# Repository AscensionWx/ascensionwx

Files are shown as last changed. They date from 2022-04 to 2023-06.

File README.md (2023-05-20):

# AscensionWx

AscensionWx is an open source weather station network supporting the Kanda Weather and U.S. and European communities. The hardware ranges from 3D-printed DIY sensors to commercially available weather stations, and aims to improve weather data collection and forecasting. 

Currently, over 100 stations are online and receiving digital rewards from the weather data they provide to the Telos Blockchain.

## Supported Ground Stations

| 3D-printed AscensionWx     |  SenseCAP LoRaWAN 8-in-1  |  SenseCAP S2101 T+RH sensor |
:-------------------------:|:-------------------------:|:-------------------------:
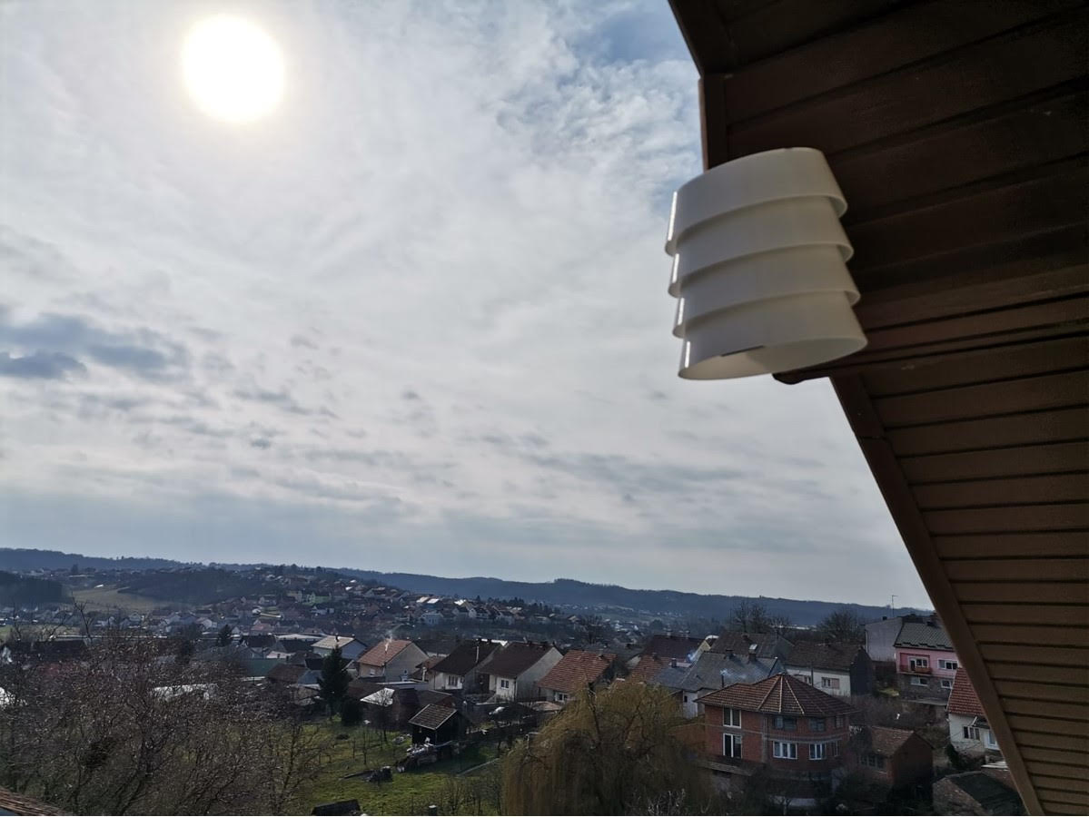
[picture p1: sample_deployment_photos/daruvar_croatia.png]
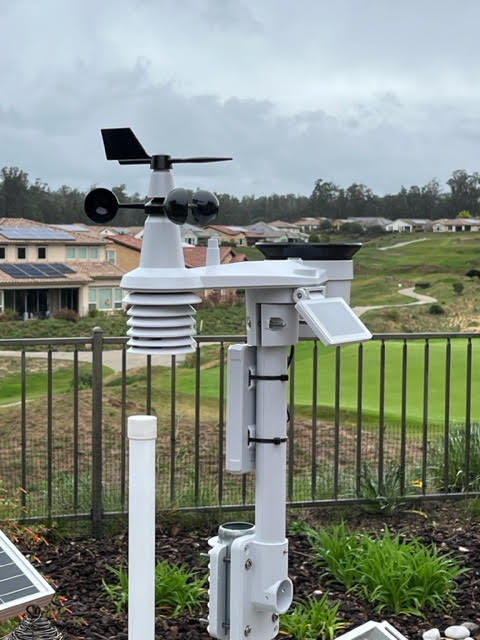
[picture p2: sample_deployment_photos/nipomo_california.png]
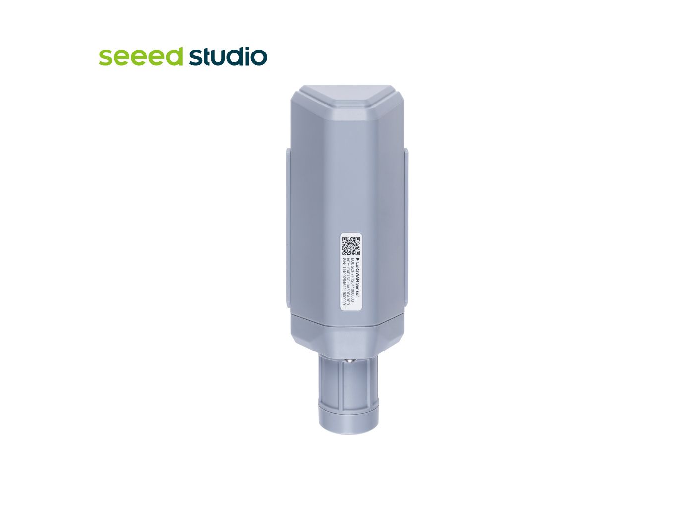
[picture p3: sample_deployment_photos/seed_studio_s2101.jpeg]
|   |   |   |

## Web Applications

Live Station Map:
- http://app.kandaweather.net:5001

Live station-specific app:
- https://ascensionwx-dashboard.vercel.app/graph?devname=brownlotguru

NFT Market (in progress):
- https://nft.kandaweather.net

## Engineering Diagram

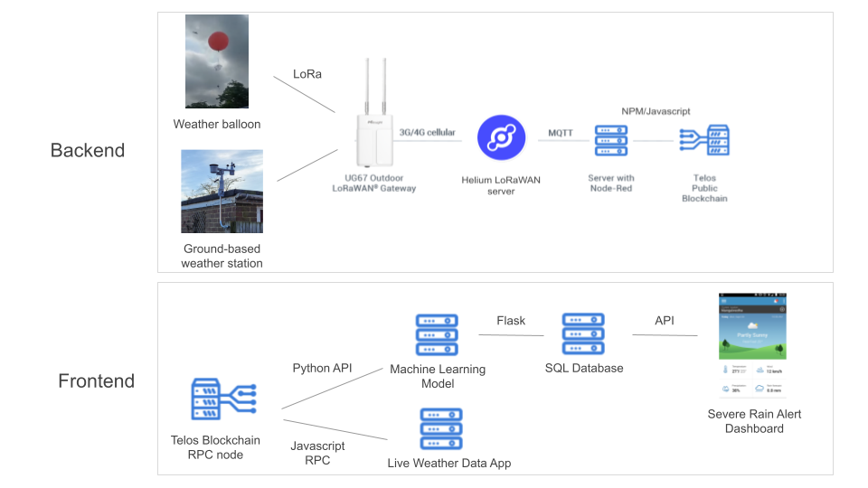
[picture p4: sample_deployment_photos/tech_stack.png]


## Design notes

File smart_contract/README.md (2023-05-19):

# Blockchain Smart Contract
The native Antelope C++ smart contract files for ground-based Weather Miners

For Kanda Weather (Africa) and AscensionWx (U.S.), and open under MIT license.

Features:
- Temperature/humidity QC quality score based on nearby stations
- Sends mining rewards to weather station owners at "Lock-In" USD rates
- Builder royalties issued for those that 3D-print stations for other users
- Sends rewards as either native or Telos EVM

Dependencies:
- 1.8.0 eosio CDT

Utilizes other on-chain contracts
- delphioracle
- eosio.evm 

Future additions:
- Device-specific digital signatures

Currently deployed as the ascendweathr contrct on Telos Mainnet
https://explorer.telos.net/account/ascendweathr

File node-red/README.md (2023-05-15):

These files are used for handling of the LoRaWAN messages. Hardware examples include:

- UG67 and UG65 Milesight IoT gateway
- Raspberry Pi
- Small AWS EC2 instance

These flows can be imported by:

1. Installing Node-RED globally
2. Updating your $HOME/.node-red/package.json file to include the following property.
```
    "dependencies": {
        "node-red-contrib-telos-eosio": <path to where you will run node-red>
    }
```
  And then run "npm install" to take effect

3. Go to the location where you want to run node-red and the flow file. Cloning external git repo
```
git clone https://github.com/sunburntcat/node-red-contrib-telos-eosio.git
```
4. Install packages
```
cd node-red-contrib-telos-eosio
npm install
```
5. Running node-red with the pre-built flow file
```
node-red <flow_filename>.json
```
6. Configuring MQTT and other nodes with appropriate credentials

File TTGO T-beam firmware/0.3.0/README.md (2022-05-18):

These files are a stable release of the Arduino-based firmware for the Kanda Weather Sensors. It includes:

- Miner authentication over the ESP32's web server
- Weather observations every 15 minutes over Helium/TheThingsNetwork
- Real time clock adjustments periodically from the GPS unit
- GPS geolocation messages during the night

Not supported:

- On-device signatures

It is recommended the user have a blank Arduino environment. And then unzip the dclimateiot_arduino_libs file in the relevant Arduino "libraries" folder.

Note that when you are ready to upload the firmware, you must first adjust the lmic_config file located in the library to match the correct frequency. 

Also note, that the correct LoRaWAN keys need to be loaded into the credentials.h file. For OTAA, DevEUI and AppEUI need to be little-endian (LSB).This can be interpretted from Helium or TheThingsNetwork consoles. The AppKEY can be big-endian.

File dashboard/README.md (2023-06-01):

## AscensionWx Live Weather Dashboard

The live weather dashboard originally written by Bayang Mounmo is being maintained in the following repository:

https://github.com/sunburntcat/ascensionwx-dashboard

Example live station page:
https://ascensionwx-dashboard.vercel.app/graph?devname=brownlotguru

Stations can be queried by typing in the name in the "Station" box. For example, to get data from the station at the University of Uyo, type "astaluniuyo1" and click the "Plot" button.

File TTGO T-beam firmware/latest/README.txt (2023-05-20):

Changes in this version:

Remove dead ABP code
Added sleep_light_millis()
Added MESSAGE_PENDING variable that gets set to false on TXCOMPLETE
Wait exactly until RX windows close after observation (saves battery)
wait_for_gps_time_and_location wait 10 seconds for GPS serial
GPS on for 5 minutes roughly every 3 days
Sends GPS message after on for 5 minutes
Remove RTC sync with every observation (was causing 1-second delay)

Todo:
GPS always 5 minutes every 3 days
GPS message 5 second wait for TX/RX output, then send
Send data every 20 minutes?

Test:

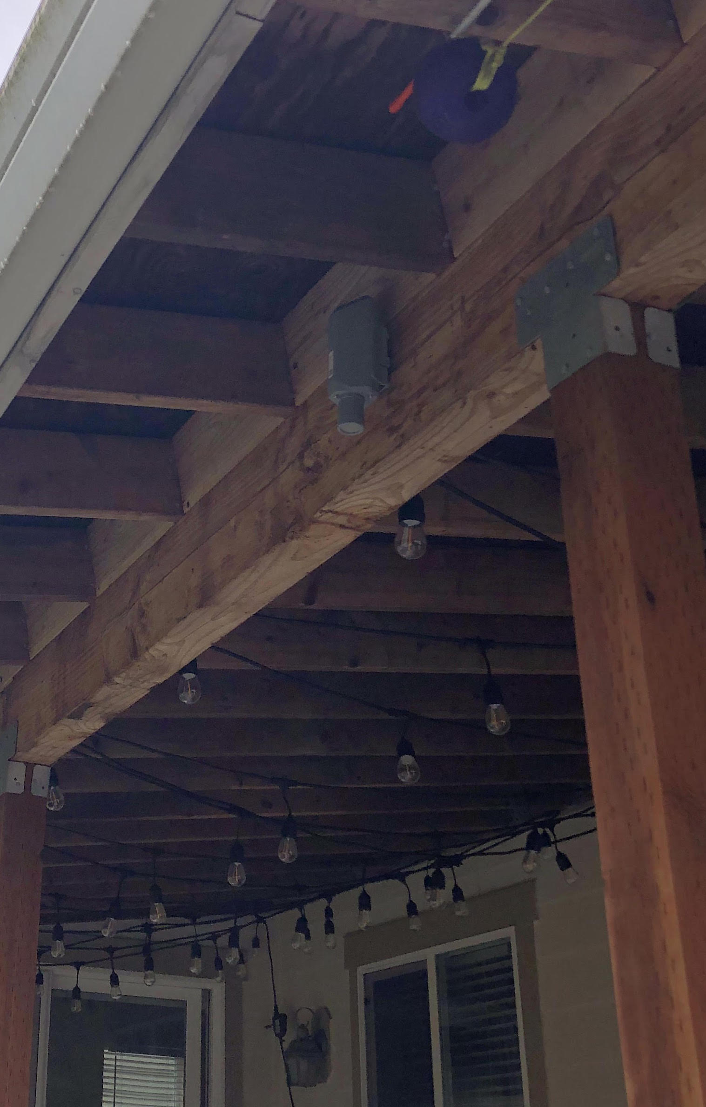
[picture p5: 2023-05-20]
sample_deployment_photos/tacoma_washington.jpeg

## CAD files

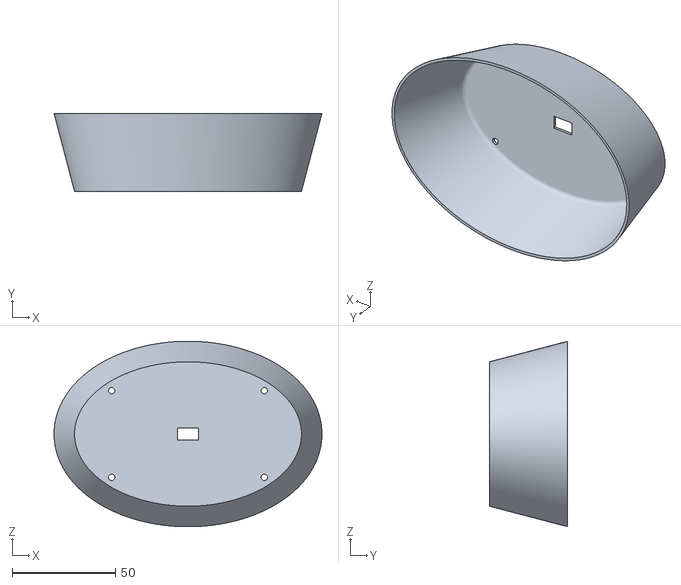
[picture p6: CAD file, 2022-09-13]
3D-print-enclosure/stl/Top.STL
129.9 x 38.0 x 89.9

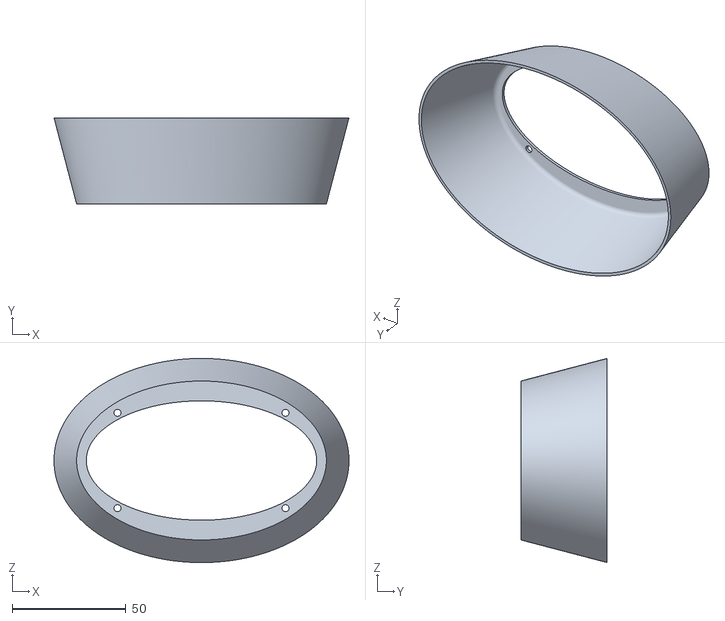
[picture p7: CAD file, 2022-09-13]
3D-print-enclosure/stl/Shroud.STL
129.9 x 38.0 x 89.9

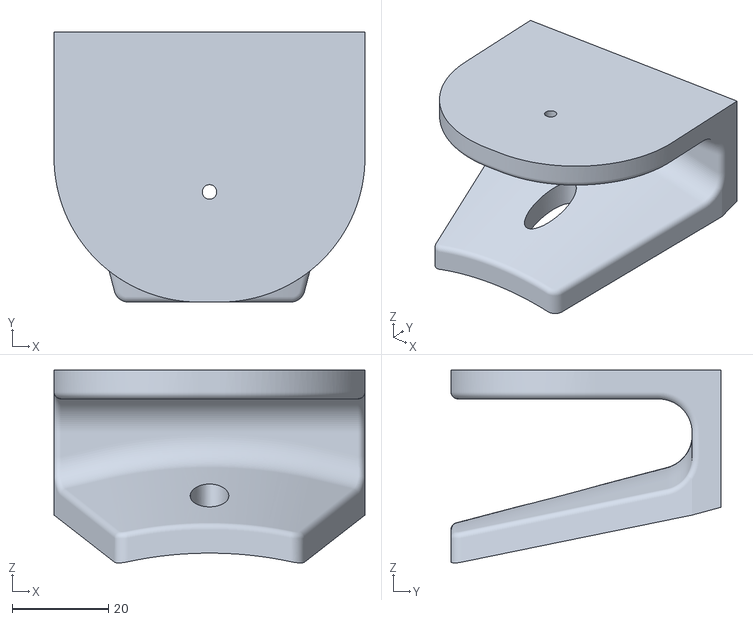
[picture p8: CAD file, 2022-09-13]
3D-print-enclosure/stl/Hook.STL
64.5 x 56.0 x 40.0

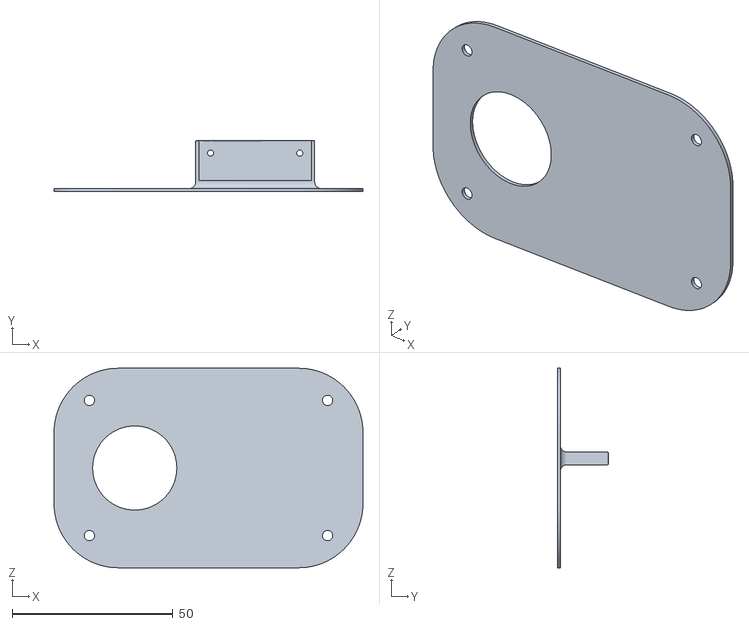
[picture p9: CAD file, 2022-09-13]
3D-print-enclosure/stl/Mid Plate.STL
96.0 x 16.0 x 62.0

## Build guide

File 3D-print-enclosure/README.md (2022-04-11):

This folder includes files used for 3D printing the 6-inch enclosure designed by Kanda.

Note that the folder "stl" includes the basic 3D CAD files. These can be viewed online or modified with commercial webapps and software. For example, TinkerCAD or Fusion360

The "gx" folder includes files for direct 3D printing. Please only use the gx files for your corresponding printer. If you have a different 3D printer, please download the files in the "stl" folder and import into a Slicer software suitable for your printer. If the prints turn out successfully, feel free to create a pull request to upload your own Sliced files to the "gx" folder.

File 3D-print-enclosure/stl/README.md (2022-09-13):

This folder includes basic CAD models

To produce a full sensor enclosure, the one needs to print multiples of some pieces. If your printer has two nozzles and a large enough print bed, you could try printing two of the items together to save time.

Here is the full list:

- 1 Top
- 3 Shroud
- 1 Mid Plate
- 1 Hook

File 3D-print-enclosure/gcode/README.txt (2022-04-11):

If you have success with printing the files, upload your Slice files here!

Place them in a folder with your printer and filament type and include a README file with a short description of your settings.

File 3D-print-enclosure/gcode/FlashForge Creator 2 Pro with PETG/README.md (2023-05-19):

All "slice" files were sliced with FlashPrint5 for the FlashForge Creator Pro 2 with PETG filament. 

Bed temperature was chosen to be 85 degrees and nozzle temperature of 240 celsius

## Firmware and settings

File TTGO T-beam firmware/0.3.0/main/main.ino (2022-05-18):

/*

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
Unless otherwise stated, all other files under this Arduino program
fall under the GPL license.

This code requires the MCCI LoRaWAN LMIC library
by IBM, Matthis Kooijman, Terry Moore, ChaeHee Won, Frank Rose
https://github.com/mcci-catena/arduino-lmic

*/

#pragma once

const char * APP_NAME = "dClimateIot";
const char * APP_VERSION = "0.3.0";

#include "config_hardware.h"

#include <Arduino.h>
#include <lmic.h>
void lorawan_register(void (*callback)(uint8_t message));

#include "soc/soc.h"
#include "soc/rtc_cntl_reg.h"

#include "config_user.h"
#include "rom/rtc.h"
#include <TinyGPS++.h>
#include <Wire.h>
#include <Math.h>
#include <axp20x.h>

#include <LoraMessage.h>
#include <LoraEncoder.h>

#include <WiFi.h>

bool SSD1306_FOUND = false;
bool BME280_FOUND = false;
bool SHT21_FOUND = false;
bool SPL06_FOUND = false;
bool AXP192_FOUND = false;
bool RELAIS_ON = false;

// Message _counter, stored in RTC memory, survives deep sleep
RTC_DATA_ATTR uint32_t COUNT = 0;

int SEND_INTERVAL;
bool GATEWAY_IN_RANGE;
String DOWNLINK_RESPONSE = "";
bool AUTHENTICATED = false;
bool BATT_CHARGING = false;
int8_t APPROX_UTC_HR_OFFSET = 0;

uint64_t last_seen_charging = 0;
uint64_t last_time_refresh = 0; // Most straight forward to store this as millis()
float time_drift = 0;
uint64_t last_gps_refresh = 0;

// Define how often to do time sync of esp32 clock with GPS
//   ... increase occurence to get better unix time stamps
//   ... decrease to save battery ; lower risk of GPS module wearing out with 1000s of on/off commands on monthly time frame
const int hr_milliseconds = 60*60*1000;
const int time_refresh_rate = hr_milliseconds*3; // How often we attempt time sync
const int wifi_on_millis = 3*60*1000;

// Launch-specific values
float SFC_PRESSURE = 0.0;
bool IF_WEB_OPENED = false;
bool IF_LAUNCHED = false;
uint8_t LAUNCH_ID[8] = { 0xFF, 0xFF, 0xFF, 0xFF, 0xFF, 0xFF, 0xFF, 0xFF } ; // For launch_id downlink

// Stores all the measured temperatures in the past 24 hours
int8_t temperatures[100];

// Set web server port number to 80
WiFiServer SERVER(80);
WiFiClient CLIENT;

// Used in power management
//  Will be used to turn off GPS, check if charging, battery etc
AXP20X_Class axp;


// -----------------------------------------------------------------------------
// Application
// -----------------------------------------------------------------------------



//////////////////////////////////////////
///////////// ARDUINO SETUP //////////////
//////////////////////////////////////////
void setup() {
  
  // Debug
  #ifdef DEBUG_PORT
  DEBUG_PORT.begin(SERIAL_BAUD);
  #endif

  // Helps to briefly wait for serial baud
  while ( millis() < 500 );
  
  Wire.begin(I2C_SDA, I2C_SCL);
  scanI2Cdevice();

  // Buttons & LED
  pinMode(BUTTON_PIN, INPUT_PULLUP);
  pinMode(LED_PIN, OUTPUT);

  // Disable brownout detector
  //WRITE_PERI_REG(RTC_CNTL_BROWN_OUT_REG, 0);

  // Display
  screen_setup();
  
  Serial.begin(115200);
  
  #ifndef IGNORE_TPRH_CHECK
  if (!if_T_and_RH_sensor() || !if_P_sensor())
  {
    screen_print("[ERR]\n");
    screen_print("No weather sensor \n");
    screen_print("connected! Check wiring.");
    Serial.println("[ERR] No weather sensor connected!");
    delay(MESSAGE_TO_SLEEP_DELAY);
    screen_off();
    sleep_forever();
  }
  #endif

  // Begin looking at AXP on I2C
  if(axp.begin(Wire, AXP192_SLAVE_ADDRESS) == AXP_FAIL) {
      Serial.println(F("failed to initialize communication with AXP192"));
  }

  // Init BME280
  bme_setup();

  // Init GPS
  gps_power_on();
  gps_setup();

  // TTN setup
  if (!lorawan_setup()) {
    screen_print("[ERR] Radio module not found!\n");
    Serial.println("[ERR] Radio module not found!");
    delay(MESSAGE_TO_SLEEP_DELAY);
    screen_off();
    sleep_forever();
  }

  lorawan_register(callback);
  lorawan_join();
  lorawan_sf(LORAWAN_SF);
  lorawan_adr(LORAWAN_ADR);
  if(!LORAWAN_ADR){
    LMIC_setLinkCheckMode(0); // Link check problematic if not using ADR. Must be set after join
  }

  // Show logo on first boot (if OLED attached)
  //screen_print(APP_NAME " " APP_VERSION " " DEVNAME " " get_freq(), 0, 0 ); // print firmware version in upper left corner
  screen_clear();

  // Print initial header at top
  char screen_buff[40];
  strncpy( screen_buff, APP_VERSION, 5 );
  strncat( screen_buff, "   ", 3 );
  strncat(screen_buff, get_devname(), 12);
  strncat( screen_buff, "   ", 3);
  strncat( screen_buff, get_freq(), 3);
  screen_print(screen_buff, 0, 0);
  
  screen_show_logo(); 
  screen_update();
  time_loop_wait( LOGO_DELAY ); // If Join_accept message received during this time, it will trigger LMIC callback function

  Serial.println();
  Serial.printf("Chip Temp: %f\n", axp.getTemp());
  Serial.printf("Chip TS Temp: %f\n", axp.getTSTemp());
  Serial.printf("Battery Percentage: %d\n", axp.getBattPercentage());

  Serial.printf("DCDC1: %s\n", axp.isDCDC1Enable() ? "ENABLE" : "DISABLE");
  Serial.printf("DCDC2: %s\n", axp.isDCDC2Enable() ? "ENABLE" : "DISABLE");
  Serial.printf("DCDC3: %s\n", axp.isDCDC3Enable() ? "ENABLE" : "DISABLE");

  if ( !GATEWAY_IN_RANGE )
  {
    // Listen for LoRaWAN response
    Serial.println("Waiting for OTAA Joined response.");
    screen_print("Please wait!\n\n");
    screen_print("Listening for LoRaWAN\n");
    screen_print("network coverage...\n");

    int time_check_start = millis();
    time_loop_wait( 5*1000 ); 
    while( !GATEWAY_IN_RANGE && !time_loop_check( time_check_start, 30*1000 ) )
    {
      send_status(true); // Receive possible missed join message or downlinks
      screen_update();
      time_loop_wait( 5*1000 );// Wait 5 seconds
    }
  }

  // Check that at least one confirmed message was received
  #if !defined(IGNORE_GATEWAY_CHECK)
  if (!GATEWAY_IN_RANGE) // If gateway still isn't in range, we cannot continue
  { 
    screen_print("[ERR]\n");
    screen_print("No LoRaWAN coverage!\n\n");
    screen_print("Please find a better\n");
    screen_print("place outdoors.\n");
    Serial.println("[ERR] LoRaWAN network not connected!");
    delay(MESSAGE_TO_SLEEP_DELAY);
    screen_off();
    gps_power_off();
    sleep_forever();
  }
  #endif

  Serial.println("LoRaWAN connected. Starting WiFi server.");
  //screen_show_qrcode();
  //screen_update();
  screen_print("LoRaWAN Connected!\n");
  screen_print("WiFi AP:  dClimateIot\n");
  screen_print("  password:  weather123\n");
  screen_print("\n");
  screen_print("Then go to  192.168.4.1\n");

  // Init wifi access point
  WiFi.softAP(SSID, PASSWORD);

  // Defines how async server handles GET requests
  //initServer();
  SERVER.begin();

  SEND_INTERVAL = 30000; // Status message this many millis
  uint32_t last = 0;

  bool enter_obs_mode = false;
  int time_check_start = millis();
  while ( !AUTHENTICATED && !enter_obs_mode ) {

    os_runloop_once();

    checkServer();
    gps_read(); // Do we need this to run so often?
    screen_loop();

    #ifdef DEBUG_MODE
      if (time_loop_check( time_check_start, wifi_on_millis )) {  // In debug mode, we start broadcasting observations after 3 minutes
         enter_obs_mode = true;
      }
    #endif
    
  }// End IF_AUTHENTICATED check

  // Close access to the server
  SERVER.end();
  // Ends wifi connection completely
  WiFi.softAPdisconnect(true);

  if (AUTHENTICATED) {
    screen_print("\nAuthentication success!\n\n");
  } else {
    screen_print("\nAuth Window closed.\n\n");
  }
  screen_print("Entering observation mode. \n");
  screen_print("  Turning off display...\n\n");
  time_loop_wait( 5*1000 ); // Wait 5 seconds so user can see message

  // Do initial clock sync before we begin
  sync_rtc_with_gps();
  calc_utc_offset();

  screen_off();
  gps_power_off(); // Cut power supply to GPS chip (saves about 20-35ma)

}// End Arduino setup() method

/////////////////////////////////////////
///////////// ARDUINO LOOP //////////////
/////////////////////////////////////////
void loop() {

  Serial.println("Sensor's unix time approximation:");
  Serial.println(get_unix_time());
  Serial.println("Approx local hour:" );
  Serial.println(get_approx_local_hour());
  Serial.println();

  uint64_t loop_start = millis();
  
  gps_read();  
  lorawan_loop();
  //screen_loop();
  
  //if (0 < gps_hdop() && gps_hdop() < 50 && gps_latitude() != 0 && gps_longitude() != 0) {

  // Warning: millis() is stored as uint32. This means integer overflow at 49 days.

  // Getting AXP temperature is best way to see if board is charging / charged recently
  // 50 Celcius is 122 degrees Farenheight
  //   -> May need toggling, particularly for cold outdoor temperatures
  if ( axp.getTemp() > 50)   
  {
    BATT_CHARGING = true;
    Serial.println("Battery charging: TRUE");
    last_seen_charging = millis();
  } else {
    BATT_CHARGING = false;
    Serial.println("Battery charging: FALSE");
  }

  if ( !time_loop_check( last_seen_charging , hr_milliseconds ) )
  {
    // TODO: Set some sort of flag here before we send the observation
    // Serial.println("AXP temperature indicates battery charging/charged recently. Flagging observation.");
  }

  send_observation();
  update_temperature_list( (uint8_t)get_temperature() );
  time_loop_wait( 2500 ); // Wait 2.5 seconds for observation message to complete

  // Note:  The subsequent send_observation() call will run asynchronously for the next two seconds.
  //   Next we update the ESP32 clock. To do whis, we turn it on, grab the time, and then turn it back off. 
  //   A full fix isn't necessarily needed to get the gps_time... the NEO6M has its
  //     own internal battery and clock that can store the GMT time for about 2 weeks.
  
  if( time_loop_check( last_time_refresh , time_refresh_rate ) )
  //if( time_loop_check( last_time_refresh , 0 ) ) // for testing
  {
    Serial.println("Beginning scheduled RTC time refresh.");
    
    // Turn on GPS
    gps_power_on();
    gps_setup();

    // Wait to get a partial fix and new timestamp from GPS
    if (wait_for_gps_time()) // returns true if GPS was able to get time
    {
      Serial.println("GPS time grabbed. Syning with ESP32 RTC.");
      sync_rtc_with_gps();
    } else {
      Serial.println("GPS time grab wait timed out.");
    }

  } else {
    Serial.println("RTC time sync not needed.");
  }

  // Finally if it's around 3am local, we do all-out GPS update
  //   - Checking 3am local time (instead of UTC) ensures it's middle of the night (better GPS reception).
  //     Also allows for location reports being spaced out in time by all sensors on the network
  //if( time_loop_check( last_gps_refresh , hr_milliseconds*3 ) ) // for testing
  if ( time_loop_check( last_gps_refresh , hr_milliseconds*2 ) && 
       ( get_approx_local_hour()==3 ) )
  {
    Serial.println("Beginning GPS refresh");

    time_loop_wait( 3000 ); // Wait more seconds to put some time between send_gps() and send_obs();
    
    // Turn on GPS
    gps_power_on();
    gps_setup();

    if (wait_for_gps_location()) // returns true if GPS was able to get location
    {
      Serial.println("GPS fix successful. Syning with ESP32 RTC.");
      sync_rtc_with_gps(); // if we got location, we can have high confidence, we also got time
      calc_utc_offset();
      send_gps();
    } else {
      Serial.println("GPS fix wait timed out.");
      send_empty_gps();
    }

    // Finally wait for lmic to finish sending GPS data
    time_loop_wait( 3000 );
    
    last_gps_refresh = millis();

  }

  // Turn off GPS in case it was on during RTC clock and GPS sync
  gps_power_off();

  // Sleep for about 15 minutes
  Serial.println("Going to sleep.");

  time_loop_wait(50);// Let Serial catch up to view messages
  uint16_t loop_time_total = (uint16_t)((millis()-loop_start)/1000);
  sleep_light_seconds( 900 - loop_time_total );
  //sleep_light_seconds( 60 - loop_time_total );
}

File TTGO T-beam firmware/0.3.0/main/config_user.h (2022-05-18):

// -----------------------------------------------------------------------------
// User Configuration
// -----------------------------------------------------------------------------

#define DEBUG_MODE 1  // Begins flight observations 2 minutes after WiFi
//#define IGNORE_GATEWAY_CHECK 1 // NOTE: Helium and other OTAA should ignore gateway check regardless
//#define IGNORE_TPRH_CHECK 1 // Uncomment to allow no I2C solder for T,P, RH

// If using a single-channel gateway, uncomment this next option and set to your gateway's channel
//#define SINGLE_CHANNEL_GATEWAY  0

#define ELEVATION_CYCLE         30000       // Used to calculate elevation_2

#define MESSAGE_TO_SLEEP_DELAY  5000        // Time after message before going to sleep
#define LOGO_DELAY              7000        // Time to show logo on first boot
#define QRCODE_DELAY            10000        // Time to show logo on first boot

#define OBSERVATION_PORT        1          // Port the obs messages will be sent to
#define GPS_LORAWAN_PORT        2
#define AUTHENTICATION_PORT     3          // Port for authentication message
#define STATUS_PORT             4          // Port the status messages will be sent to

#define LORAWAN_CONFIRMED_EVERY 0           // Send confirmed message every these many messages (0 means never)
#define LORAWAN_SF              DR_SF10     // Spreading factor
#define LORAWAN_ADR             0           // Enable ADR

#define MISSING_UINT            0
#define MISSING_FLOAT           0

//Wifi defines
const char* SSID     = "dClimateIot";
const char* PASSWORD = "weather123";

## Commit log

2022-09-13 Taylor Initial version
    [Hook.STL, Mid Plate.STL, Shroud.STL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]
2022-09-13 Taylor initial commit
    [Hook.STL, Mid Plate.STL, Shroud.STL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]
2023-05-19 Update flow_May19_2023.json
    Includes ground sensors, MeasEarth, radiosonde for all Helium and TTN devices

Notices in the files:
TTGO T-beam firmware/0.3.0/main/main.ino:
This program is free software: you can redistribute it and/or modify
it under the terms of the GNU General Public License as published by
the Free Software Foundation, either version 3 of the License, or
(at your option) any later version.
